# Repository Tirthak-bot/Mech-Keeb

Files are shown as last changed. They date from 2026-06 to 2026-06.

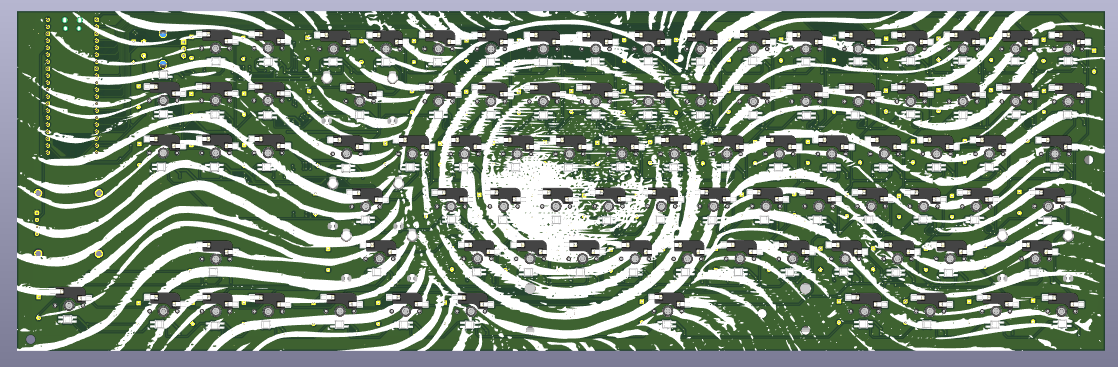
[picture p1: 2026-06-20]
PCB/PCB Images/PCB Back With Components.png

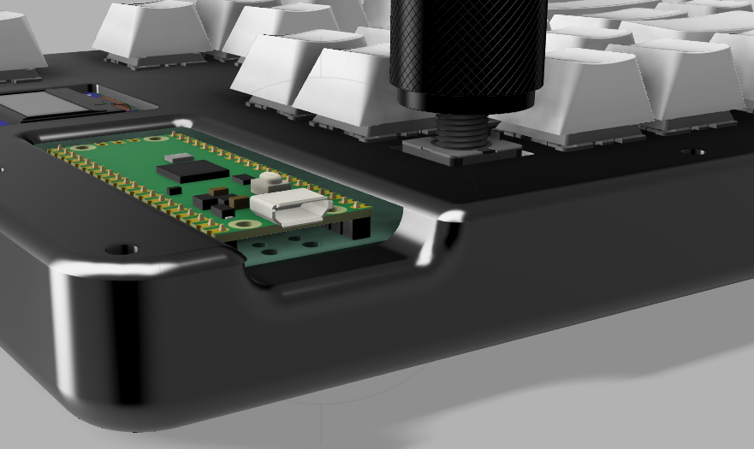
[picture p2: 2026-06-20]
Renders/Render-1.png

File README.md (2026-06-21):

# Mech-Keeb
A Almost Full Sized Mechanical Keyboard, Hot Swappable Switches and coded in KMK Firmware!
<br>

Mech Keeb Zine
Render Compilation

<br>

Making this keyboard because i don't have a *almost full sized decent Keyboard!
<br>
<br>
Using this is pretty straight forward obviously blehh, just connect it to the computer, flash the firmware once and it should just work like a regular keeb moving forward :)

# Schematic
The Schematic was made in KICAD!
<br>

Schematic_page-0001

# Layout
The layout was designed on https://www.keyboard-layout-editor.com/, The firmware hasn't yet been edited to match this layout and is currently sitting with placeholders, I will do it once i get the parts irl. Also the Blank keys will be used as arrow keys and macro keys.
<br> 



# PCB
The PCB was designed in KICAD!
<br> 

PCB Front
PCB Front With Components
PCB Back
PCB Back With Components

# Case
The case was designed in Fusion. PCB to the bottom case and bottom case to top case all is joined by M3 Screws!
<br>

Anyways, here is a ugly ahh blue render of the case bleh :3

40209db7-113f-4d1a-9cf5-38ee7798f177

# Firmware
As mentioned above, the firmware is written in python using the KMK Libraries. It will be pushed to the microcontroller using circuit python.

# BOM
|SR.NO|ITEMS|QUANTITY|UNIT PRICE|TOTAL PRICE|URL|
|-----|-----|---|---|---|---|
|1|	PCB|	5	|$25|	$125|	https://www.lioncircuits.com/|
|2| 1N4148 1W Zener Diode|	100|	$0.016	|$1.67	|https://robu.in/product/1n4148-1w-zener-diode-pack-of-50/|
|3|	1N5819 1W Diode|	5	|$0.03	|$0.15|	https://robu.in/product/1n5819-1w-diode-pack-of-30/|
|4|	0402 100nf Capacitors SMD|	100|	$0.021|	$2.1	|https://robu.in/product/tcc0402x7r104j500at-cctc-smt-ceramic-capacitors-0402-x7r-104j100nf%C2%B15-0-rated-voltage50v-thickness0-50mm-tape/|
|5|	SK6812 Mini-E	|200|$0.13	|$27	|https://desertcart.in/products/690911592|
|6|	RPI PICO|	1	|$4.1	|$4.1	|https://robu.in/product/raspberry-pi-pico/|
|7|	0.96 inch I2C OLED Display|	1|	$2.12|	$2.12	|https://robu.in/product/0-96-inch-i2c-iic-oled-lcd-module-4pin-with-vcc-gnd-blue/|
|8|	Cherry MX Style Switches|	2 Sets|	$16|	$32|	https://stackskb.com/store/akko-fairy-pro-switch-pack-of-45/|
|9|	EC11 Rotary Encoder|	1	|-|	-|	Self Sourced|
|10|	Hot Swap Sockets	|90	|$0.11|	$9.6|	https://stackskb.com/store/gateron-hotswap-sockets/|
|11|	Keyboard Stabilizers	|1 Set| (4 + 1; 6.25U)|	$17|	$17|	https://stackskb.com/store/durock-clear-screw-in-stabilizers-v2/|
|12|	Keycaps	|1 Set	|$14|	$14|	https://stackskb.com/store/veekos-gradient-keycaps-cherry-profile-135-keys/|
|13|	Assorted M3 Screws|	-|	-|	-|	Self Sourced|
|14|	M3 Heat Inserts	|-|	-	|-	|Self Sourced|
|15|	Filament Spool(For 3D Printing the case)|	1 Roll|	$8	|$11|	https://india.numakers.com/products/pla-metallic#|
|16|	A Set of tweezers|	1 Set|	$2	|$2	|https://robu.in/product/anti-static-tweezers-6pcs-set-vetus-bga-esd/|
||TOTAL:||			$250||

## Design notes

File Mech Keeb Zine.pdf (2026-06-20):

# KEYBOARD

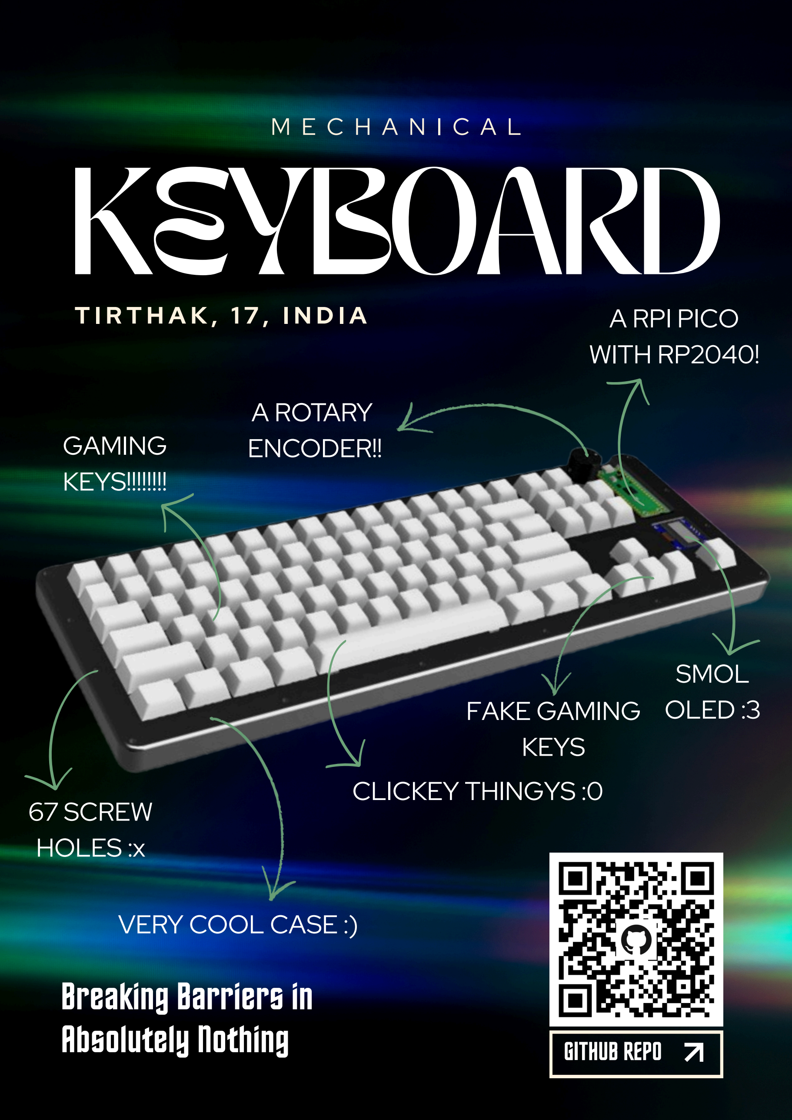
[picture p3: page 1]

GITHUBREPO

SMOL
FAKE GAMING OLED :3
KEYS

M E C H A N I C A L

### BreakingBarriersin AbsolutelyNothing

A ROTARY
ENCODER!!

A RPI PICO
WITH RP2040!

CLICKEY THINGYS :0

GAMING
KEYS!!!!!!!!

VERY COOL CASE :)

67 SCREW
HOLES :x

T I R T H A K , 1 7 , I N D I A

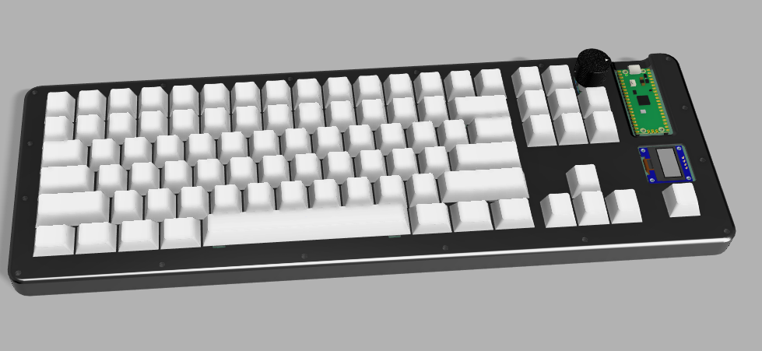
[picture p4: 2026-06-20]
Renders/Render-2.png

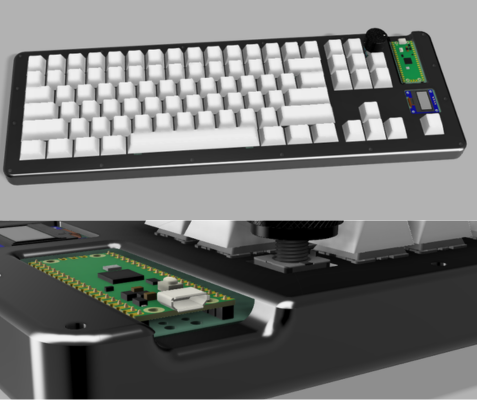
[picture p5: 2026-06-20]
Renders/Render Compilation.png

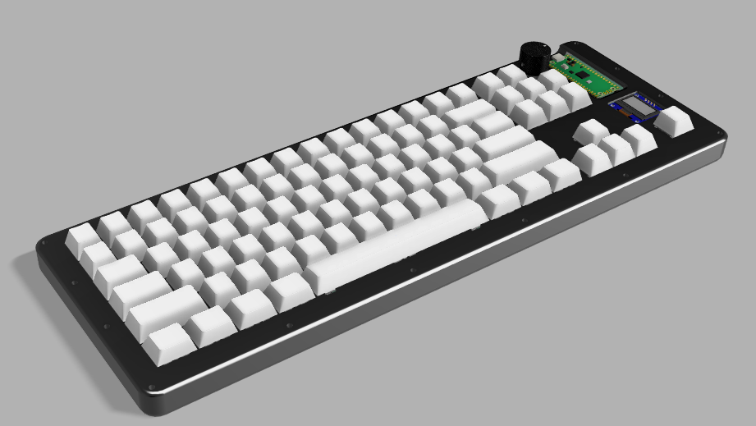
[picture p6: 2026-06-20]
Renders/Render-3.png

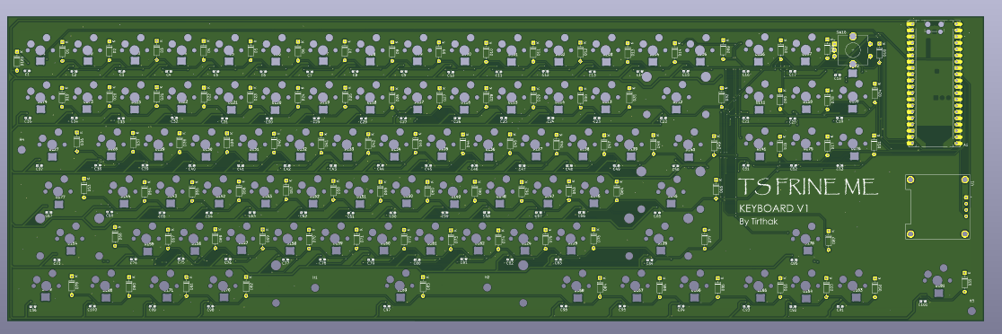
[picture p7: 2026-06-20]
PCB/PCB Images/PCB Front.png

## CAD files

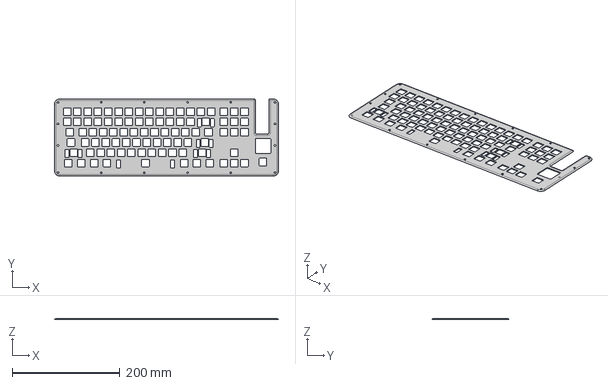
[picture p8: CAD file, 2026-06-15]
CAD/Case/Intact Files/Mechanical Keyboard Top Case - Intact.step
415.0 x 143.4 x 1.50 mm

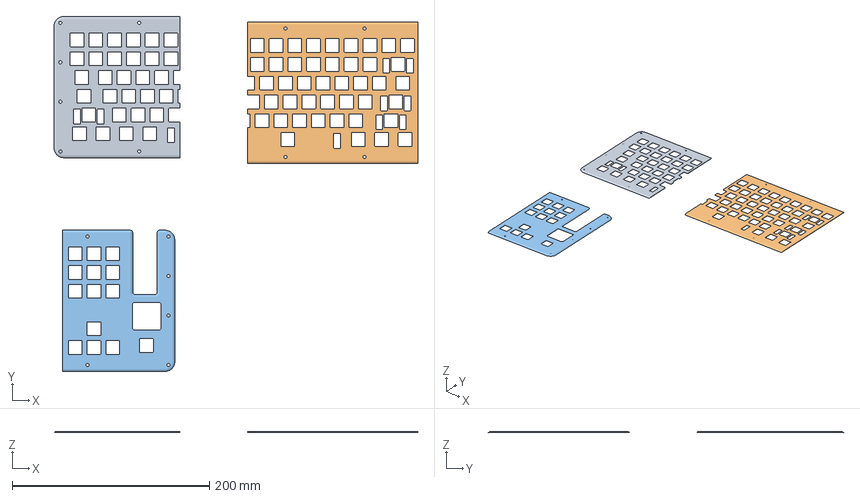
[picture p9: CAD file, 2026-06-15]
CAD/Case/Printing Files/Mechanical Keyboard Top Case - For Printing.3mf
369.3 x 360.2 x 1.50 mm
Mechanical Keyboard Top Case - Intact.step_A
Mechanical Keyboard Top Case - Intact.step_B_A
Mechanical Keyboard Top Case - Intact.step_B_B

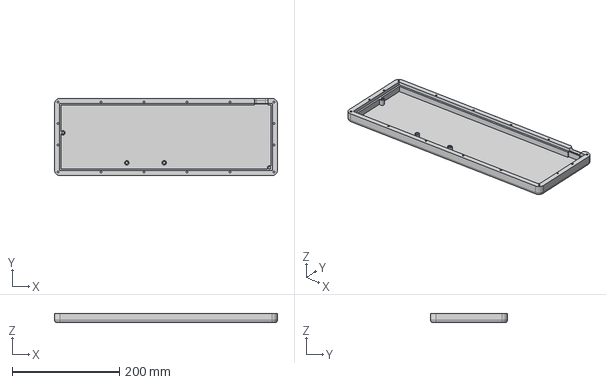
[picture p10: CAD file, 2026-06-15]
CAD/Case/Intact Files/Mechanical Keyboard Bottom Case - Intact.step
415.0 x 143.4 x 17.6 mm

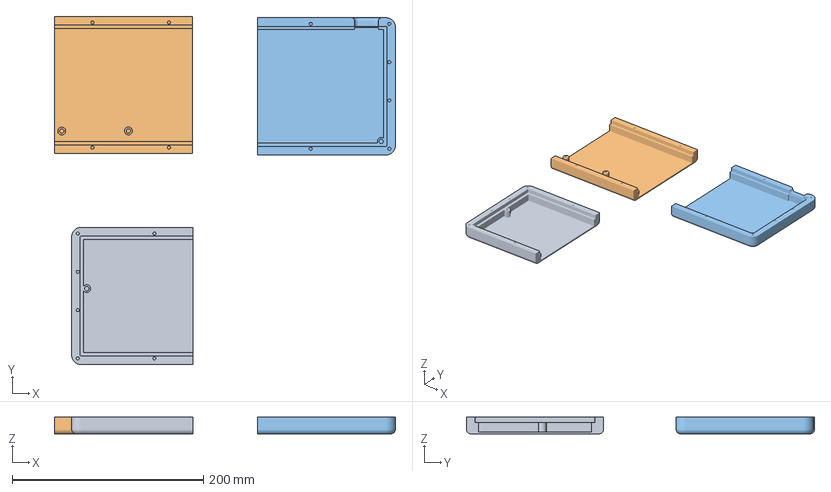
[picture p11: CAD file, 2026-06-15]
CAD/Case/Printing Files/Mechanical Keyboard Bottom Case - For Printing.3mf
356.2 x 363.7 x 17.6 mm
Mechanical Keyboard Bottom Case - Intact.step_A
Mechanical Keyboard Bottom Case - Intact.step_B_A
Mechanical Keyboard Bottom Case - Intact.step_B_B

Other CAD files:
CAD/Extras/PCB.step
CAD/Case/Printing Files/Mechanical Keyboard Bottom Case - For Printing.stl
CAD/Case/Printing Files/Mechanical Keyboard Top Case - For Printing.stl
CAD/Fusion-Project/Mechanical-Keyboard.f3z

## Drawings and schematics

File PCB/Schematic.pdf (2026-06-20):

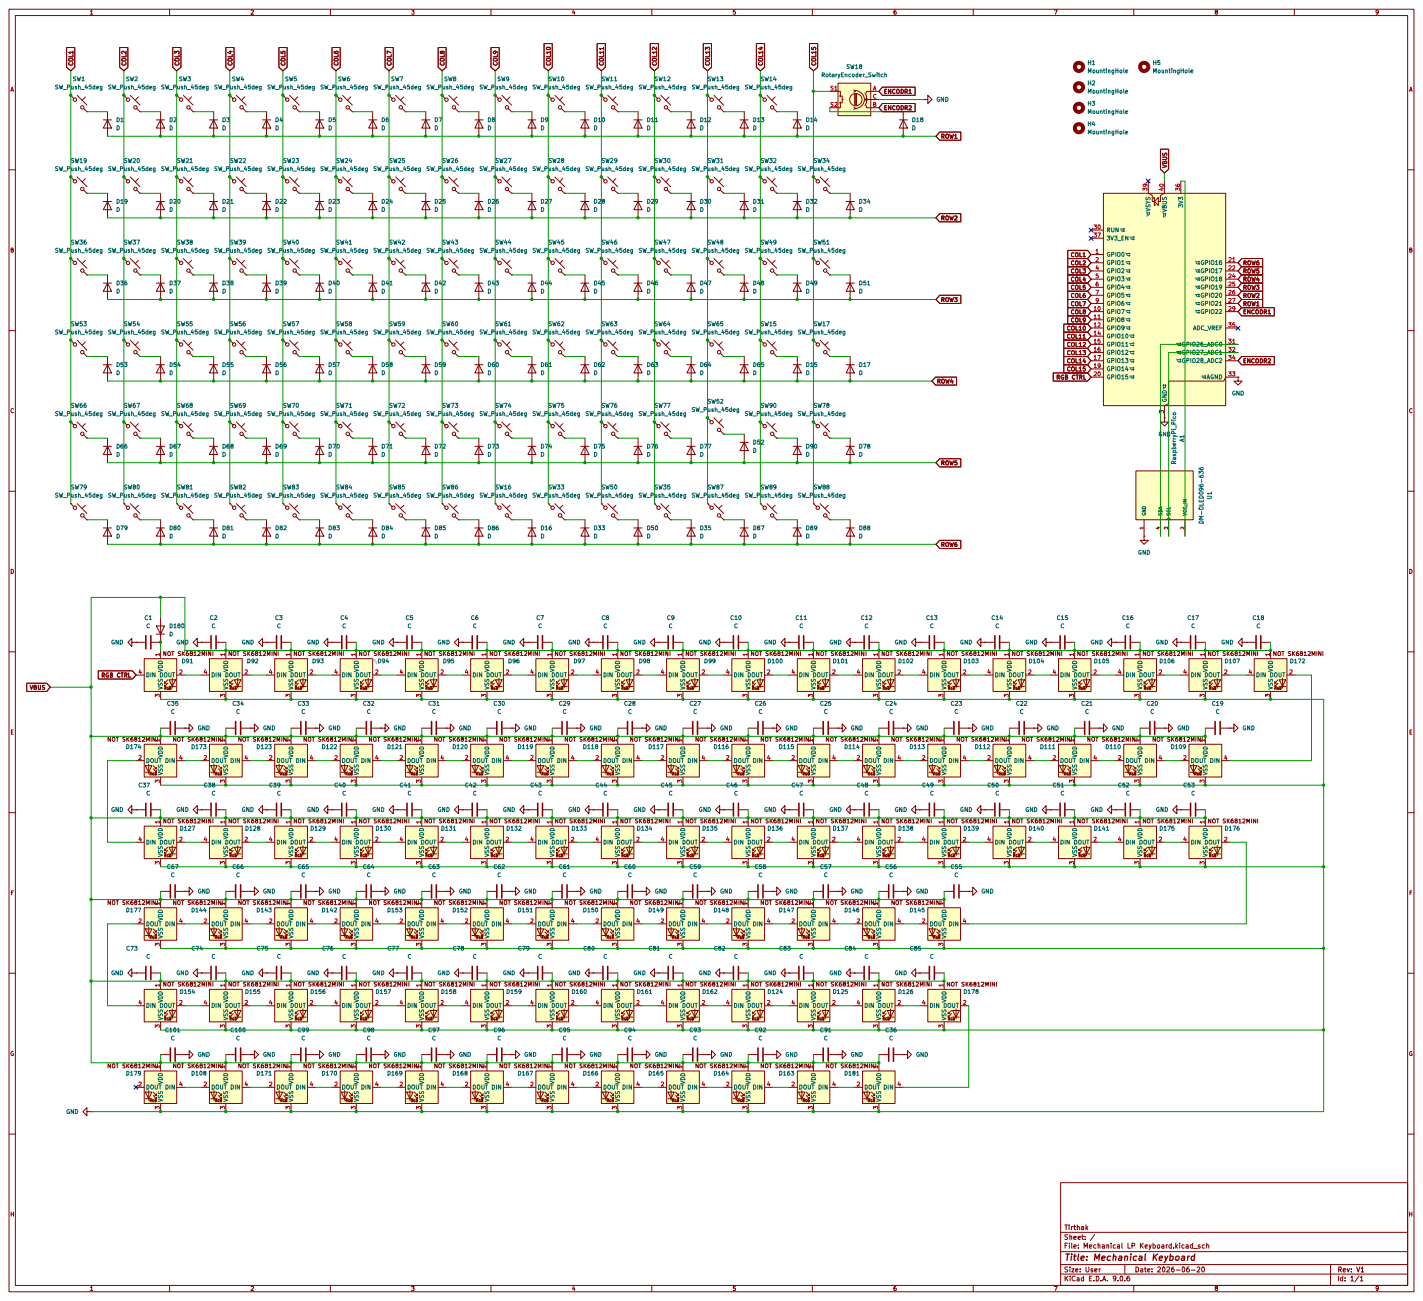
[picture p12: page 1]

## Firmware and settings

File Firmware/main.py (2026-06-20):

import board
import digitalio
import busio

from kmk.kmk_keyboard import KMKKeyboard
from kmk.scanners import DiodeOrientation
from kmk.keys import KC
from kmk.extensions.rgb import RGB
from kmk.extensions.oled import Oled, OledData
from kmk.modules.encoder import EncoderHandler

keyboard = KMKKeyboard()

keyboard.col_pins = (
    board.GP0, board.GP1, board.GP2, board.GP3, board.GP4,
    board.GP5, board.GP6, board.GP7, board.GP8, board.GP9,
    board.GP10, board.GP11, board.GP12, board.GP13, board.GP14,
)
keyboard.row_pins = (
    board.GP15, board.GP16, board.GP17, board.GP18, board.GP19,
    board.GP20,
)
keyboard.diode_orientation = DiodeOrientation.COL2ROW

encoder_handler = EncoderHandler()
encoder_handler.pins = ((board.GP21, board.GP22, board.GP23),)  # adjust pins
encoder_handler.map = [
    ((KC.VOLU, KC.VOLD),)  
]
keyboard.modules.append(encoder_handler)

rgb = RGB(
    pixel_pin=board.GP24,   # DIN pin for SK6812 LEDs
    num_pixels=90,          # adjust to number of LEDs in schematic
    hue_default=180,
    sat_default=255,
    val_default=100,
)
keyboard.extensions.append(rgb)

oled = Oled(
    i2c=busio.I2C(board.GP25, board.GP26),  # SDA, SCL pins
    width=128,
    height=64,
    flip=False,
)
keyboard.extensions.append(oled)
def draw(oled_data: OledData):
    oled_data.text("Hi :3", 0, 0)


keyboard.keymap = [
    [
        KC.ESC, KC.Q, KC.W, KC.E, KC.R, KC.T, KC.Y, KC.U, KC.I, KC.O, KC.P, KC.BSPC, KC.NO, KC.NO, KC.NO,
        KC.TAB, KC.A, KC.S, KC.D, KC.F, KC.G, KC.H, KC.J, KC.K, KC.L, KC.SCLN, KC.ENT, KC.NO, KC.NO, KC.NO,
        KC.LSFT, KC.Z, KC.X, KC.C, KC.V, KC.B, KC.N, KC.M, KC.COMM, KC.DOT, KC.SLSH, KC.RSFT, KC.NO, KC.NO, KC.NO,
        KC.LCTL, KC.LGUI, KC.LALT, KC.SPC, KC.RALT, KC.RGUI, KC.RCTL, KC.NO, KC.NO, KC.NO, KC.NO, KC.NO, KC.NO, KC.NO, KC.NO,
    ]
]

if __name__ == '__main__':
    keyboard.go()

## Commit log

2026-06-20 adding fusion file
    [Mechanical-Keyboard.f3z]
2026-06-20 adding pcb.step
    [PCB.step]
